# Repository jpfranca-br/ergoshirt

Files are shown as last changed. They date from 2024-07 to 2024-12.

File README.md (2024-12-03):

# ErgoShirt  

This project was developed as part of the *IoT for Digital Transformation* course in the **Master in Digital Transformation (MDT)** program at PUC-Rio. It explores an IoT-enabled t-shirt designed to assist in improving body posture, combining technology with practical health benefits.  

## Project Overview  

The repository includes:  
- **Source Code**: Implementation of the IoT system.  
- **Connection Diagrams**: Schematics for setting up hardware.  
- **Blynk Dashboard Examples**:  
  - [Mobile](https://raw.githubusercontent.com/jpfranca-br/ergoshirt/main/images/blynk%20mobile%20console.jpg)  
  - [Web](https://raw.githubusercontent.com/jpfranca-br/ergoshirt/main/images/blynk%20web%20console.jpg)  
- **[Product Presentation](https://github.com/jpfranca-br/ergoshirt/tree/main/presentation)**: Details of the project goals and outcomes.  
- **[Architecture](https://github.com/jpfranca-br/ergoshirt/tree/main/architecture)**: System design and technical overview.  

### Important Note  
This project is a **Proof of Concept (PoC)**. Parameters for the Blynk platform and WiFi provisioning are hardcoded for simplicity.  

---

## Contributors
- **Professor**: [Dra. Débora Cardador](https://www.linkedin.com/in/debora-cardador/)
- **Team Members**:
  - [Ana Paula Marcatto](https://www.linkedin.com/in/ana-paula-marcatto-627a84257/)  
  - [Fabio Silva](https://www.linkedin.com/in/fabio-silva-6674baa/)  
  - [Gustavo Fontinha](https://www.linkedin.com/in/gustavo-fontinha-7209a13/)  
  - [João Paulo M. França](https://www.linkedin.com/in/jpfranca)  
  - [Luis Jairo de Souza Jr](https://www.linkedin.com/in/luisjairojr/)  
  - [Mauricio Stelling](https://www.linkedin.com/in/mauriciostelling/)  
  - [Rodrigo Uchôa](https://www.linkedin.com/in/rcuchoa/)  
  - [Silmar Reis](https://www.linkedin.com/in/silmar-reis/)  

---

## Demo  

Experience the **ErgoShirt prototype** in action by watching this [demo video](https://github.com/jpfranca-br/ergoshirt/raw/main/video/demo.mp4).  

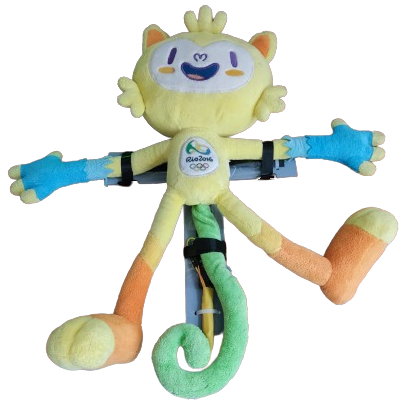
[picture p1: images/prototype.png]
ErgoShirt Prototype


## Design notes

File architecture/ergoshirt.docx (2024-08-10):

# Arquitetura do Sistema ErgoShirt

## I. Identificação do Produto e da Equipe

### Produto

ErgoShirt – sua camisa inteligente para correção postural

### Equipe

Fabio Silva, Luis Jairo Jr, Mauricio Stelling, Silmar Reis, João França, Gustavo Fontinha, Ana Paula Marcatto, Rodrigo Uchôa

## II. Dispositivos e Serviços

### Controlador

Placa de Desenvolvimento ESP32 C3 Super Mini Conectividade: WIFI & Bluetooth LE Processador: RISC-V Single-Core CPU Comunicação/Alimentação: USB Tipo C Alimentação: 5V D (step-down) ou 3.3V DC Memória: Flash 4MB IO: 12x IO bidirecionais, com ADC de 12 bits em 4 delas. I2C, SPI, UART A leitura dos sensores, processamento e decisão sobre ativação dos atuadores ocorre localmente. A conexão à plataforma é necessária para alteração de parâmetros e envio de informações, a serem acompanhadas pelo cliente e seu fisioterapeuta. | Valor FOB importação direta da China R$ 15,00

### Sensores e Atuadores

Sensor Flexível Resistivo Impermeável Varia a resistência de acordo com a pressão. Aplicado com um divisor resistivo nas portas ADC do microcontrolador. Modelo: ZD10-100 Comprimento: 100mm Largura: 10mm Faixa: 0 ~ 500g Espessura: menos de 0.25mm Resposta ponto: menos de 20g Tensão de teste: 3.3V DC típico Durabilidade: mais de 1 milhão vezes Tempo de resposta: 10ms Tempo de recuperação: menos de 15ms Temperatura de trabalho: - 20 oC ~ 60 oC Peso: 3g | Valor FOB importação direta da China R$ 20,00
Atuador – Mini motor de vibração Alimentação: 3.3V DC | R$ 5,00

### Outros

Alimentação Bateria 3.3V ou 5V DC. Para o protótipo foi usada a saída USB (5V DC) de um Powerbank de 10000 mAh, permitindo vários dias de operação. | Variável
Camiseta justa ao corpo O protótipo foi montado e uma base de ABS levemente flexível para facilitar o manuseio. O produto final deve ser costurado a uma camisa justa ao corpo. | Variável
Misc Resistores 10kOhm, fios elétricos, costura | ~0

### Serviços

Firmware do controlador Código em C++ desenvolvido pela equipe conforme registrado no GitHub (https://github.com/jpfranca-br/ergoshirt). Para comunicação com a nuvem foi usada principalmente a biblioteca BlynkSimpleEsp32.h (https://github.com/blynkkk/blynk-library/blob/master/src/BlynkSimpleEsp32.h) | Dev Interno
Plataforma Plataforma Blynk (https://blynk.io/), que oferece suporte à conexão de dispositivos IOT via Wi-Fi (diretamente para a plataforma) ou Bluetooth (se comunicando com o app Blynk) com sua nuvem proprietária, além da construção de dashboards, atualização OTA e outras facilidades. Poderíamos explorar soluções abertas como https://thingsboard.io/, mas não o fizemos em benefício do tempo, por já termos familiaridade com Blynk. | R$ 35 / mês Plano maker - personal (https://blynk.io/pricing)

## III. Conexão e comunicação

A conexão pode ser feita de 2 formas principais:

1) Diretamente do dispositivo IOT, que tem WiFi integrado, à nuvem da plataforma. Essa conexão foi implementada para o protótipo.
2) Conectando o dipositivo IOT, que tem BlueTooth integrado, a um aparelho celular rodando o app Blynk Android ou iOS e, a partir dele, à nuvem da plataforma. Não implementamos no protótipo mas, pela facilidade de conexão do BlueTooth, essa parece ser uma escolha melhor para a entrada em produção.

## IV. Aplicações

Aplicativo Móvel Dashboard construído sobre o app Android (https://play.google.com/store/apps/details?id=cloud.blynk) da plataforma Blynk (https://blynk.io/). Bidirecional, servindo tanto para configurar parâmetros (variações admissíveis na leitura de cada sensor, período do ciclo de leitura, período do ciclo para envio de informações à nuvem) quanto exibir as leituras atuais e passadas dos sensores, assim como o estado dos atuadores. | Custo incluído na plataforma
Aplicativo Web Dashboard construído na plataforma web Blynk (https://blynk.io/), com as mesmas características informadas acima. | Idem

## V. Dispositivos e serviços que compõem a arquitetura do sistema

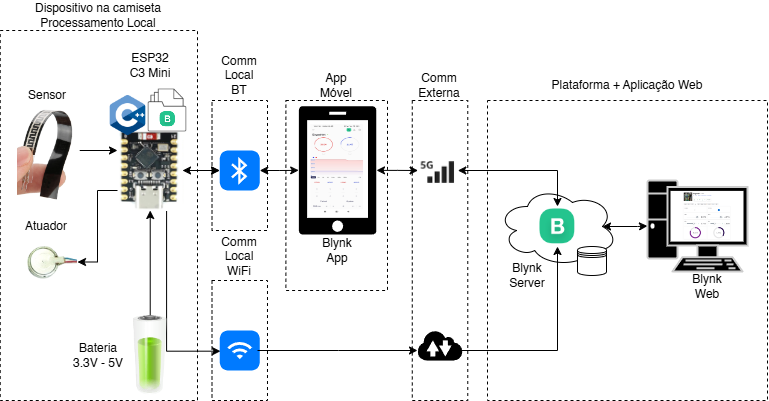
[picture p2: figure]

## VI. Informações Adicionais

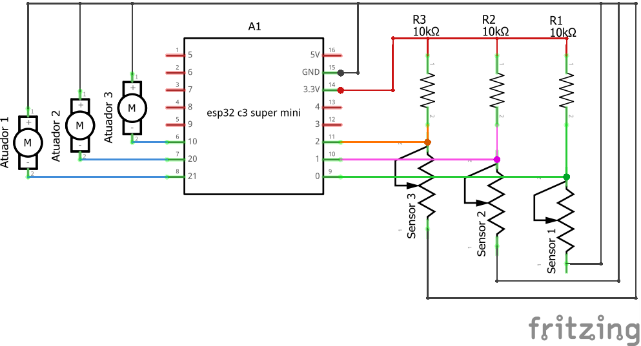
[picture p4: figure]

Pinout ESP32 C3 Super Mini | Esquemático para 3 sensores/atuadores

### Ligações Realizadas

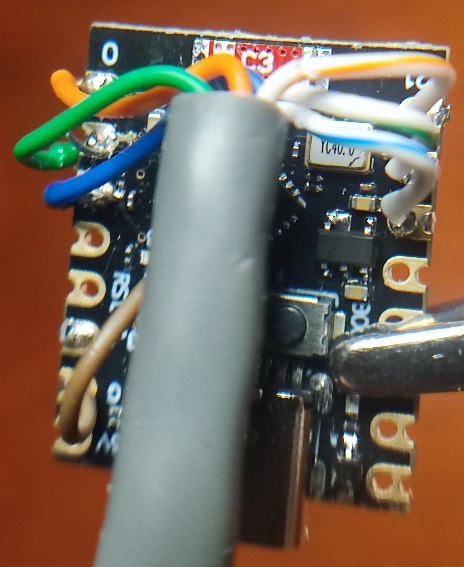
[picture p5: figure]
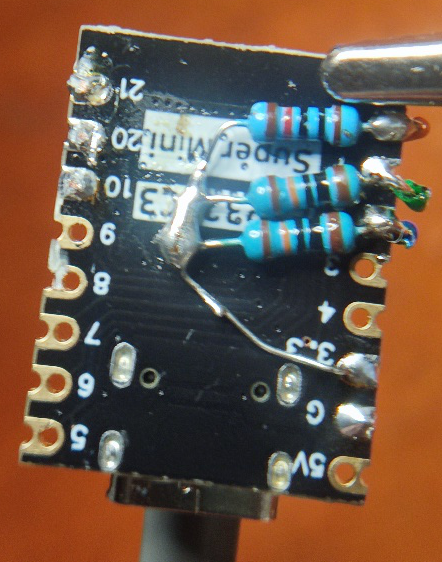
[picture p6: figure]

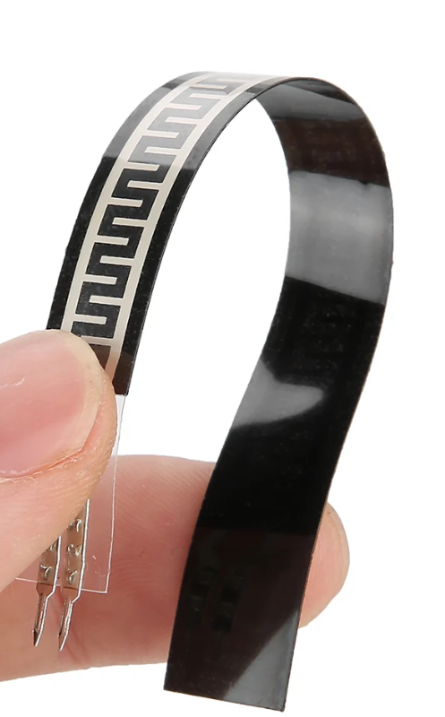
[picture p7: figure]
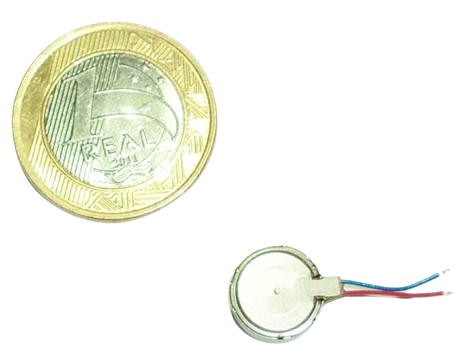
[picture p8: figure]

Sensor Flexível | Mini Motor

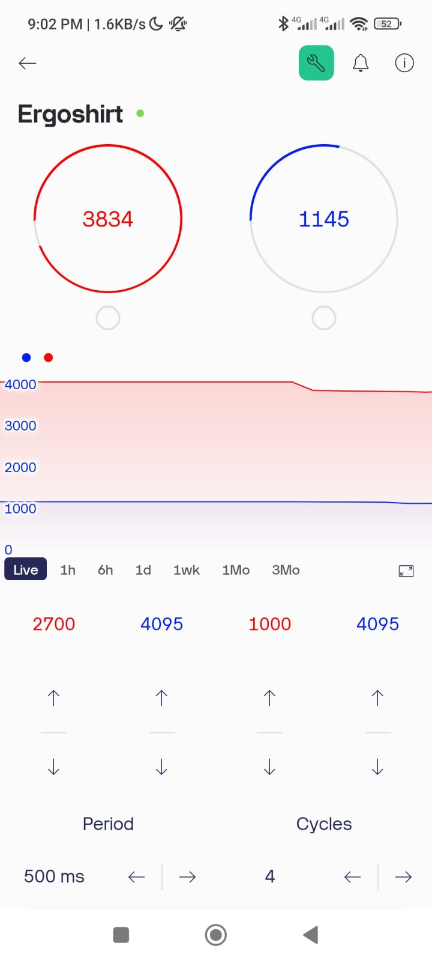
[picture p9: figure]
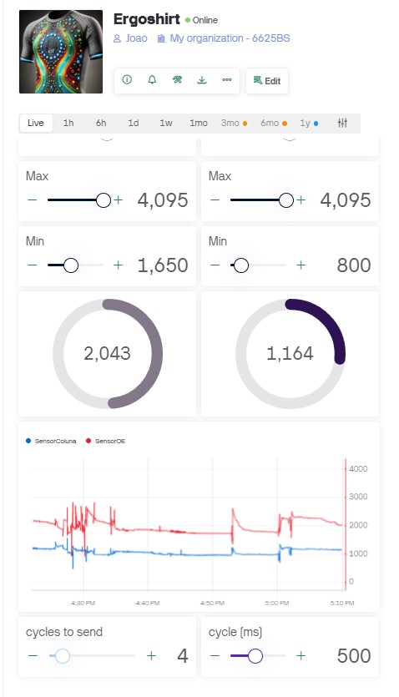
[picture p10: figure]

Console Mobile | Console Web

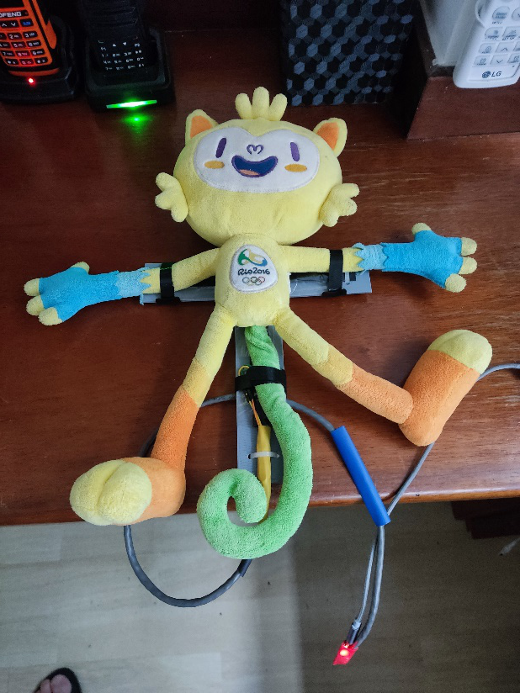
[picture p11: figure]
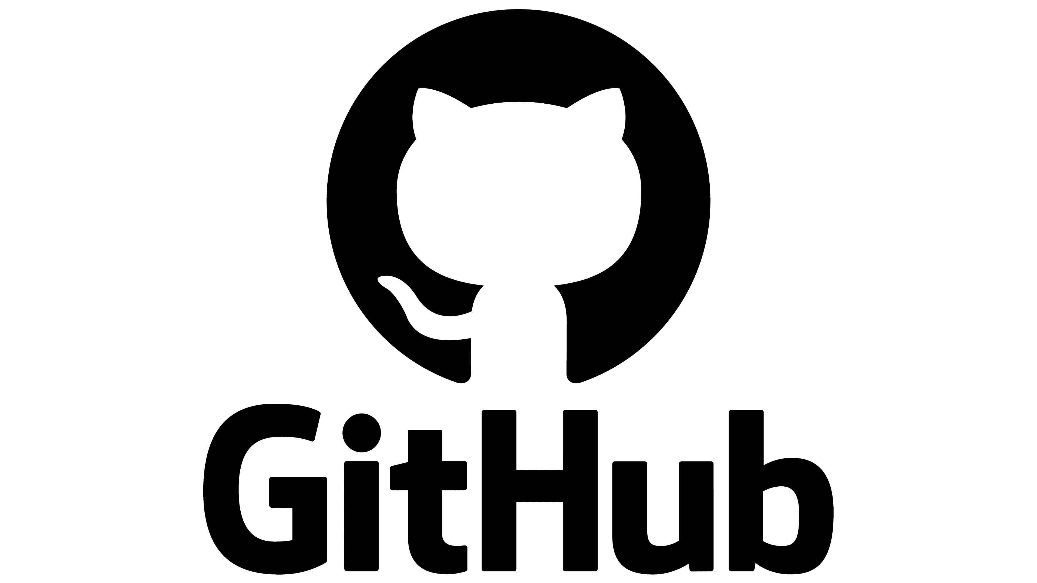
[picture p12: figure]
GitHub Logo and symbol, meaning, history, PNG, brand

Vinícius, nosso protótipo funcional / Mascote | Código-Fonte, Apresentação e Outras informações

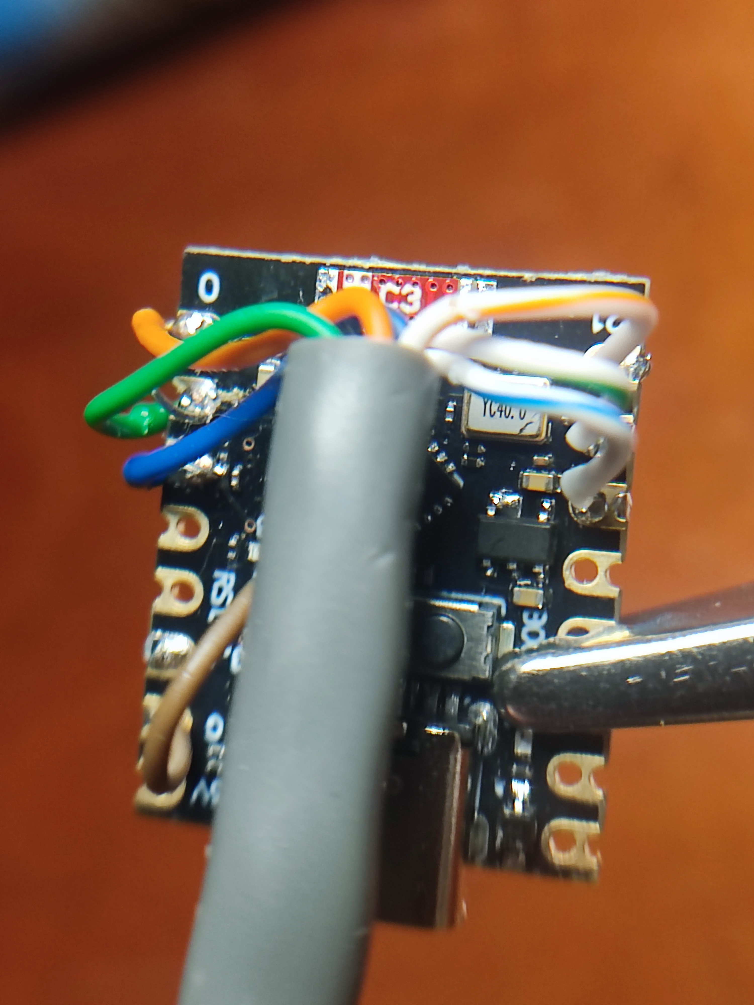
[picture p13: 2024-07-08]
images/esp32 c3 supermini with wires attached.jpg

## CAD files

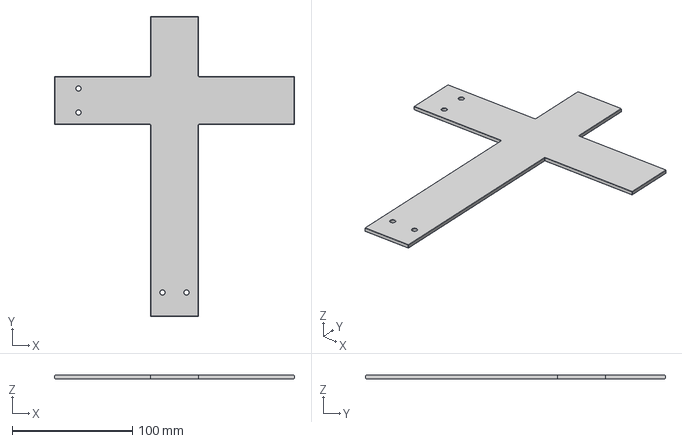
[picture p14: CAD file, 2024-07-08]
3dmodel/suporte.3mf
200.0 x 250.0 x 3.00 mm

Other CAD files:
3dmodel/suporte.f3d

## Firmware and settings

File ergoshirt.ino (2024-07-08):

// Blynk Device Info
#define BLYNK_TEMPLATE_ID "<FILL_IN>"
#define BLYNK_TEMPLATE_NAME "<FILL_IN>"
#define BLYNK_AUTH_TOKEN "<FILL_IN>"
#define BLYNK_PRINT Serial

// Debugging functionality
#define DEBUG // Comment to turn off debugging
#ifdef DEBUG
  #define PRINT(x) Serial.print(x)
#else
  #define PRINT(x)
#endif

// Include Libraries for WiFi and Blynk
#include <WiFi.h>
#include <WiFiClient.h>
#include <BlynkSimpleEsp32.h>

// WiFi Credentials
// Set password to "" for open networks.
char ssid[] = "<FILL_IN>";
char pass[] = "<FILL_IN>";

// Timer settings
#define TIMER_PERIOD 500L // Period in milliseconds (500 ms)
#define SENDING_INTERVAL 4 // Number of periods before sending average readings to Blynk

// Number of sensors and actuators
#define NUMBER_OF_SENSORS 3

// Pin configuration for ESP32-C3 SuperMini
const int ANALOG_PIN[NUMBER_OF_SENSORS] = {0, 1, 2};
const int DIGITAL_PIN[NUMBER_OF_SENSORS] = {21, 20, 10};

// Blynk virtual pins
const int TERMINAL_PIN = V0;
const int SENDING_INTERVAL_PIN = V1;
const int TIMER_PERIOD_PIN = V2;
const int VIRTUAL_PIN_SENSOR[NUMBER_OF_SENSORS] = {V10, V20, V30};
const int VIRTUAL_PIN_ACTUATOR[NUMBER_OF_SENSORS] = {V11, V21, V31};
const int VIRTUAL_PIN_MAX[NUMBER_OF_SENSORS] = {V12, V22, V32};
const int VIRTUAL_PIN_MIN[NUMBER_OF_SENSORS] = {V13, V23, V33};

// Minimum gap between maximum and minimum values (hysteresis)
const int MIN_GAP = 100;

// Initialize variables
int sensor[NUMBER_OF_SENSORS];
int sensorAccumulator[NUMBER_OF_SENSORS];
int targetMax[NUMBER_OF_SENSORS] = {4095, 4095, 4095};
int targetMin[NUMBER_OF_SENSORS] = {2047, 2047, 2047};
int sendingInterval = SENDING_INTERVAL;
int timerPeriod = TIMER_PERIOD;
bool actuator[NUMBER_OF_SENSORS];
bool previousActuator;
int j = 0;
int timerId;

// Create Timer class
BlynkTimer timer;

// Blynk function to handle virtual pin writes
BLYNK_WRITE_DEFAULT() {
  int pinValue = param.asInt();
  int pinNumber = request.pin;
  
  // Update target max and min values from Blynk
  for (int i = 0; i < NUMBER_OF_SENSORS; i++) {
    if (VIRTUAL_PIN_MAX[i] == pinNumber) {
      targetMax[i] = pinValue;
      if (targetMax[i] - targetMin[i] < MIN_GAP) {
        targetMax[i] = min(targetMin[i] + MIN_GAP, 4095);
        Blynk.virtualWrite(VIRTUAL_PIN_MAX[i], targetMax[i]);
      }
      break;
    }
    if (VIRTUAL_PIN_MIN[i] == pinNumber) {
      targetMin[i] = pinValue;
      if (targetMax[i] - targetMin[i] < MIN_GAP) {
        targetMin[i] = max(targetMax[i] - MIN_GAP, 0);
        Blynk.virtualWrite(VIRTUAL_PIN_MIN[i], targetMin[i]);
      }
      break;
    }
  }
  
  // Update interval and period settings
  if (pinNumber == SENDING_INTERVAL_PIN) { 
    sendingInterval = pinValue; 
  } else if (pinNumber == TIMER_PERIOD_PIN) {
    timerPeriod = pinValue;
    timer.changeInterval(timerId, timerPeriod);
  }
  
  // Print received value to terminal
  terminal("Valor recebido no Pin " + String(pinNumber) + ": " + String(pinValue) + "\n");
}

// Function to print messages to Blynk terminal
void terminal(String message) {
  PRINT(message);
  Blynk.virtualWrite(TERMINAL_PIN, message);
}

// Function to read analog sensors
void readSensors() {
  PRINT(String(j * timerPeriod) + "ms - #" + String(j) + "/" + String(j) + " - ");
  for (int i = 0; i < NUMBER_OF_SENSORS; i++) {
    sensor[i] = analogRead(ANALOG_PIN[i]);
    sensorAccumulator[i] += sensor[i];
    PRINT(String(i) + ": " + String(sensor[i]) + ", ");
  }
  PRINT("\n");
}

// Function to check sensor values and update actuators
void checkInRange() {
  for (int i = 0; i < NUMBER_OF_SENSORS; i++) {
    previousActuator = actuator[i];
    actuator[i] = (sensor[i] > targetMax[i]) || (sensor[i] < targetMin[i]);
    if (previousActuator != actuator[i]) {
      Blynk.virtualWrite(VIRTUAL_PIN_ACTUATOR[i], actuator[i]);
      digitalWrite(DIGITAL_PIN[i], actuator[i]);
    }
  }
}

// Alternative function to check sensor values and update actuators
void checkInRange_alt() {
  for (int i = 0; i < NUMBER_OF_SENSORS; i++) {
    previousActuator = actuator[i];
    actuator[i] = (sensor[i] > targetMax[i]) || (sensor[i] < targetMin[i]);
    if (previousActuator != actuator[i]) {
      Blynk.virtualWrite(VIRTUAL_PIN_ACTUATOR[i], actuator[i]);
    }
  }
  
  bool compare = false;
  for (int i = 0; i < NUMBER_OF_SENSORS; i++) {
    compare = compare || actuator[i];
  }
  for (int i = 0; i < NUMBER_OF_SENSORS; i++) {
    digitalWrite(DIGITAL_PIN[i], compare);
  }
}

// Function to calculate average sensor readings and send to Blynk
void sendToBlynk() {
  if (j >= sendingInterval) {
    PRINT("\nEnviando para a Blynk após " + String(j) + " leituras de " + String(timerPeriod) + " ms\n");
    for (int i = 0; i < NUMBER_OF_SENSORS; i++) {
      Blynk.virtualWrite(VIRTUAL_PIN_SENSOR[i], sensorAccumulator[i] / j);
      String message = String(sensorAccumulator[i] / j) + "(" + String(targetMin[i]) + "," + String(targetMax[i]) + ") | ";
      PRINT(message);
    }
    PRINT("\n\n");
    j = 0;
    for (int i = 0; i < NUMBER_OF_SENSORS; i++) { sensorAccumulator[i] = 0; }
  }
}

// Function to check Blynk connection and reconnect if needed
void checkBlynk() {
  if (!Blynk.connected()) {
    PRINT("Blynk não conectado. Tentando reconectar...");
    Blynk.connect();
  }
}

// Main function to be called periodically by the timer
void mainFunction() {
  j++;
  readSensors();
  checkInRange_alt();
  checkBlynk();
  sendToBlynk();
}

// Setup function
void setup() {
  // Initialize Serial for debugging
  Serial.begin(115200);

  // Configure pins
  for (int i = 0; i < NUMBER_OF_SENSORS; i++) {
    pinMode(ANALOG_PIN[i], INPUT);
    pinMode(DIGITAL_PIN[i], OUTPUT);
  }

  // Connect to WiFi and Blynk
  Blynk.begin(BLYNK_AUTH_TOKEN, ssid, pass);

  // Setup timer to call mainFunction periodically
  timerId = timer.setInterval(timerPeriod, mainFunction);

  // Sync initial values from Blynk and send default variables
  Blynk.run();
  Blynk.syncAll();
  terminal("Iniciando\n");
  Blynk.virtualWrite(V1, sendingInterval);
  Blynk.virtualWrite(V2, timerPeriod);
}

// Main loop
void loop() {
  Blynk.run();
  timer.run();  // Run BlynkTimer
}
